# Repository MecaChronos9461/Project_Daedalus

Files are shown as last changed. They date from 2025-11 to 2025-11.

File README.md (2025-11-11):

# Project_Daedalus

# 🌍 Project Daedalus - Projeto Dédalo

Welcome! / Bem-vindo!

🇺🇸 Assistive Technology for Accessible CNC Programming Education (SENAI Vila Leopoldina + FRC 9461 MecaChronos

🇧🇷 Tecnologia Assistiva para o Ensino Acessível de Programação CNC (SENAI Vila Leopoldina + FRC 9461 MecaChronos)

**Choose your language / Escolha o idioma:**

- 🇺🇸 [English version](docs/en/index.md)
- 🇧🇷 [Versão em português](docs/pt/index.md)

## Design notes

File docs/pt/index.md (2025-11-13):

# Projeto Dédalo – Tecnologia Assistiva para o Ensino de CNC em Braille

**SENAI Vila Leopoldina + FRC 9461 MecaChronos**

Transforma o ensino de CNC e programação em uma experiência tátil e acessível.

[🇬🇧 Read in English](../en/index.md)

---

## 🎯 Visão Geral
O **Projeto Dédalo** transforma o ensino de CNC e de linguagens de programação em uma experiência **tátil e inclusiva**.  
Permite que estudantes cegos ou com baixa visão construam programas CNC utilizando **peças em Braille** sobre um **tabuleiro imantado**, representando a estrutura de comandos reais (G-code e lógica).

## 🧩 Guia Rápido
1. Acesse o [Guia Rápido](guia-rapido.md)
2. Baixe e imprima as peças 3D da pasta [`/stl`](https://github.com/MecaChronos9461/Project_Daedalus/tree/main/STL/pt)  
7. Monte o **tabuleiro imantado e as peças em Braille** (veja [Montagem Mecânica](https://github.com/MecaChronos9461/Project_Daedalus/blob/main/docs/pt/Projeto_Dedalo_Montagem.pdf)) 

## 🔗 Links Úteis
- [Onshape (CAD paramétrico)](https://cad.onshape.com/documents/f621f9364d6d382a1512dc64/w/f1545546a1fff06d9537397c/e/68e42de75a9061a4f078c312)
- [Tinkercad (modelos simplificados)](https://www.tinkercad.com/things/3EPu3dX8Huk-templatededalo)
- [Google Drive (manuais e PDFs)](https://drive.google.com/drive/folders/1ncHGz5KKSIpBdTNndNMXi23kKEn_FBrG?usp=sharing)

## 🧠 Objetivos
- Tornar o ensino de CNC e programação **acessível** a pessoas cegas ou com baixa visão  
- Fornecer um **kit educacional modular** com peças em Braille e documentação aberta  
- Apoiar docentes com **planos de aula, arquivos CAD e modelos STL**

## ⚙️ Licença
Distribuído sob **Creative Commons BY-SA 4.0**.  
Consulte o arquivo [LICENSE](../../LICENSE) para mais detalhes.

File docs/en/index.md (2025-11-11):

# Project Daedalus – Assistive Technology for Accessible CNC Education

**SENAI Vila Leopoldina + FRC 9461 MecaChronos**

Inclusive CNC programming through tactile Braille pieces and a magnetic board.

[🇧🇷 Read in Portuguese](../pt/index.md)

---

## 🎯 Overview
Project Daedalus transforms CNC and programming education into a **tactile and inclusive experience**.  
It allows students who are blind or visually impaired to build CNC programs using **Braille blocks** arranged on a **magnetic board**, simulating the structure of real G-code and logic.

## 🧩 Quick Start
1. Visit the [Quick Start Guide](quickstart.md)  
2. Download and print the 3D pieces from the [`/stl`](../../stl/) folder  
3. Assemble the **magnetic board and Braille blocks** (see [Mechanical Assembly](section-06_mechanical-assembly.md))  
4. Try the examples in [`/examples`](../../examples/) for your first lesson  

## 🔗 Useful Links
- [Onshape (CAD source)](../links.md#onshape)
- [Tinkercad (simplified models)](../links.md#tinkercad)
- [Google Drive (manuals and PDFs)](../links.md#google-drive)

## 🧠 Objectives
- Make CNC/programming education **inclusive** for blind and low-vision students  
- Provide a **modular educational kit** with Braille-based blocks and open documentation  
- Support teachers with ready-to-use **lesson plans, CAD files, and STL models**

## ⚙️ License
This project is distributed under **Creative Commons BY-SA 4.0**.  
See the [LICENSE](../../LICENSE) file for full details.

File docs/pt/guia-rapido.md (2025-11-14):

## 🧭 Guia Rápido

1. **Acesse o repositório principal:**  
   [GitHub - Projeto Dédalo](https://github.com/MecaChronos9461/Project_Daedalus)

2. **Baixe os arquivos 3D:**  
   [📂 STL](https://github.com/MecaChronos9461/Project_Daedalus/tree/main/STL/pt)

2. **Baixe os arquivos do tabuleiro:**  
   [📂 DWG](https://github.com/MecaChronos9461/Project_Daedalus/tree/main/SVG/pt)

3. **Monte o tabuleiro imantado e as peças em Braille:**  
   [🧩 Guia de Montagem Mecânica](https://github.com/MecaChronos9461/Project_Daedalus/blob/main/docs/pt/Projeto_Dedalo_Montagem.pdf)

4. **Assista aos tutoriais e veja como editar as peças:**  
   [🎥 Vídeos no YouTube](https://www.youtube.com/@FRC9461MecaChronos)

5. **Consulte os manuais e relatórios:**  
   [📘 Documentação Completa (PDF)](https://github.com/MecaChronos9461/Project_Daedalus/tree/main/docs/pt/desenhos_CAD)

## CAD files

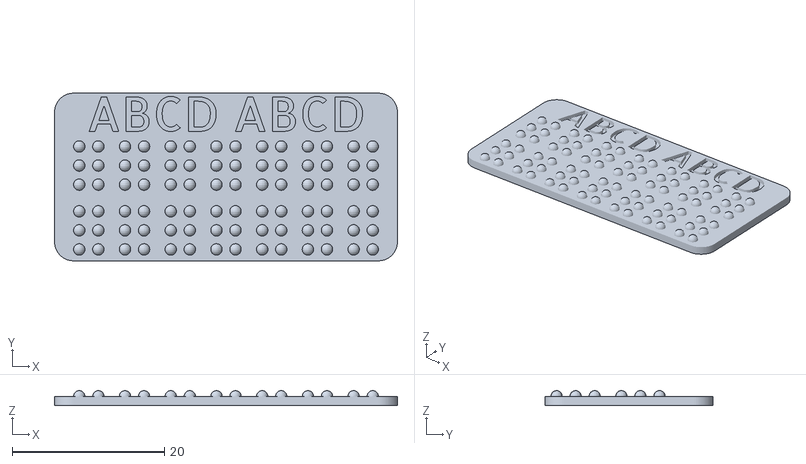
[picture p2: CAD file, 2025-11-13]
STL/pt/Etiqueta_2_Peças.stl
45.0 x 22.0 x 1.95

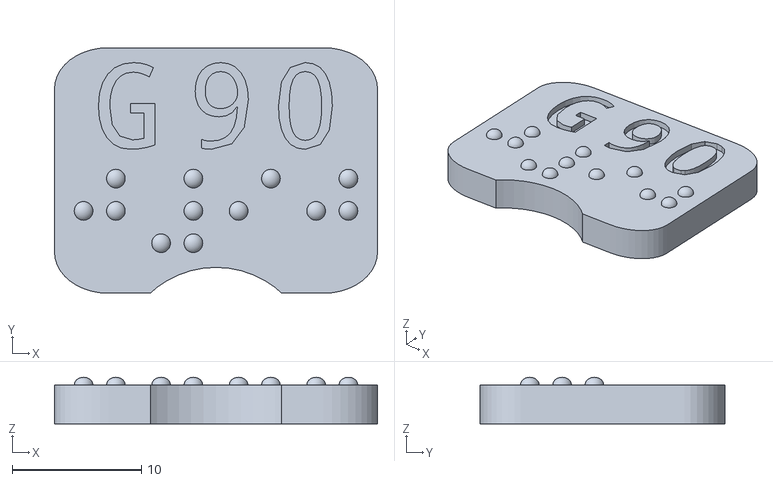
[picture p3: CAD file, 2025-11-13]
STL/pt/Pecas_GCODE/G90.stl
25.0 x 19.0 x 3.60

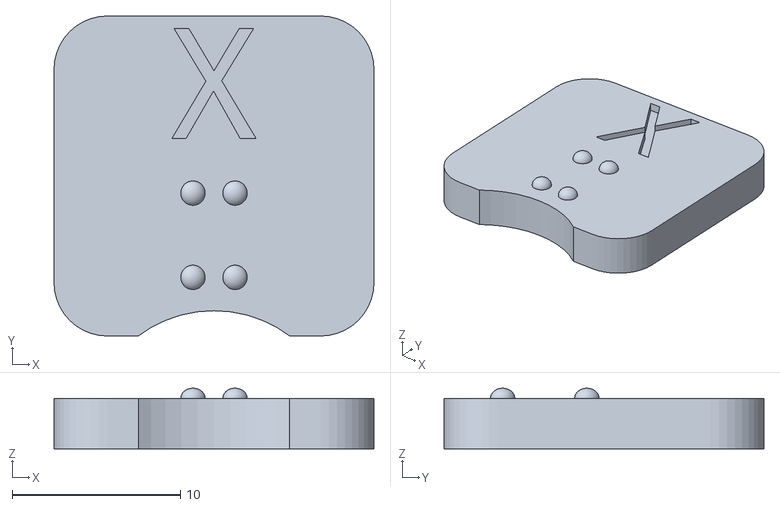
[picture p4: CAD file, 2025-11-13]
STL/pt/Pecas_Letras/X.stl
19.0 x 19.0 x 3.60

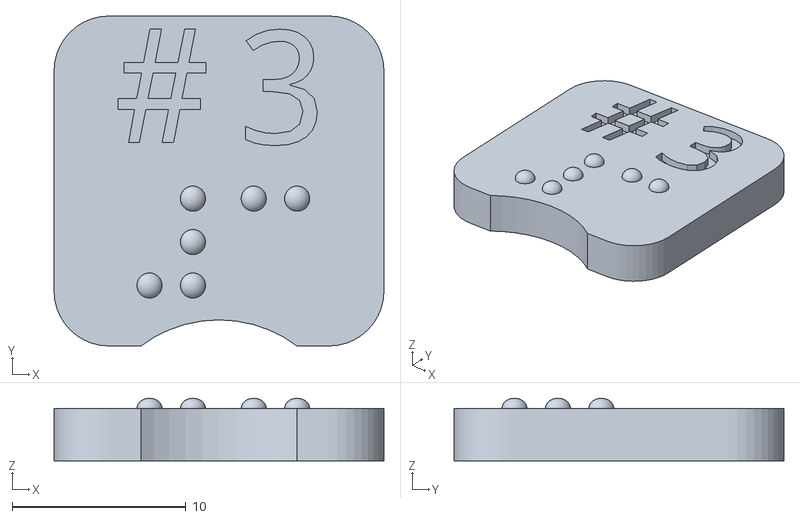
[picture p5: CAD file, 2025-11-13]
STL/pt/Pecas_Numeros/3.stl
19.0 x 19.0 x 3.60

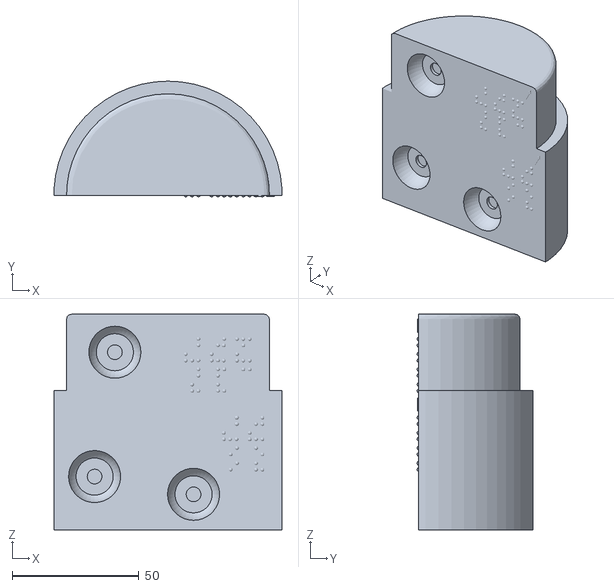
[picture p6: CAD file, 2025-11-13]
STL/pt/Pecas_Referencia/PEÇA_BLANK_LADO_1.stl
89.9 x 45.6 x 85.0

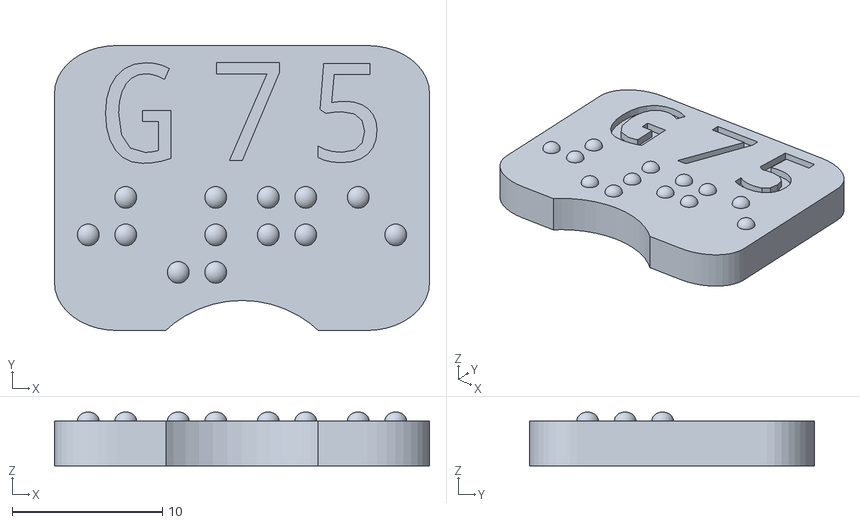
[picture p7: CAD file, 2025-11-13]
STL/pt/Pecas_GCODE/G75.stl
25.0 x 19.0 x 3.60

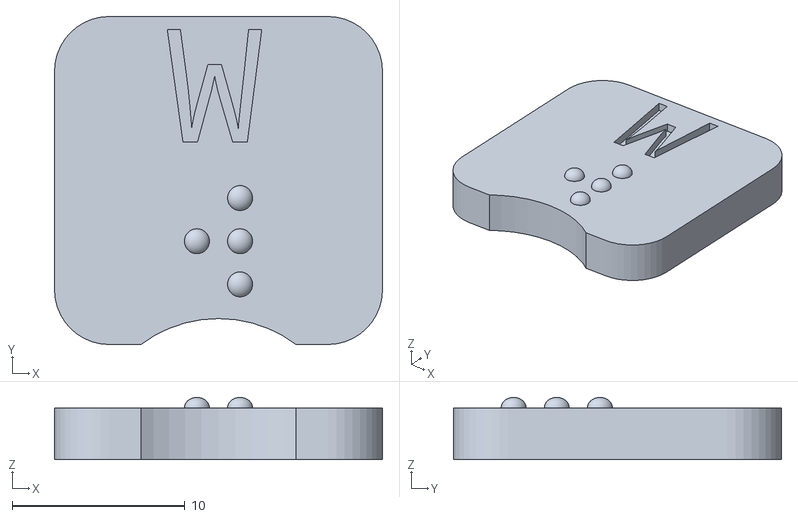
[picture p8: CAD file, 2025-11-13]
STL/pt/Pecas_Letras/W.stl
19.0 x 19.0 x 3.60

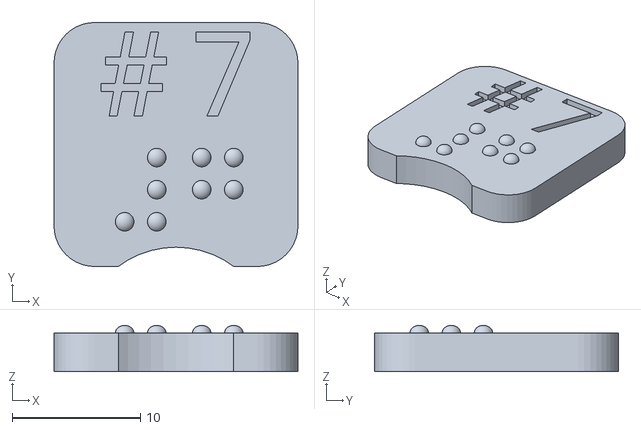
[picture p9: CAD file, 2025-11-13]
STL/pt/Pecas_Numeros/7.stl
19.0 x 19.0 x 3.60

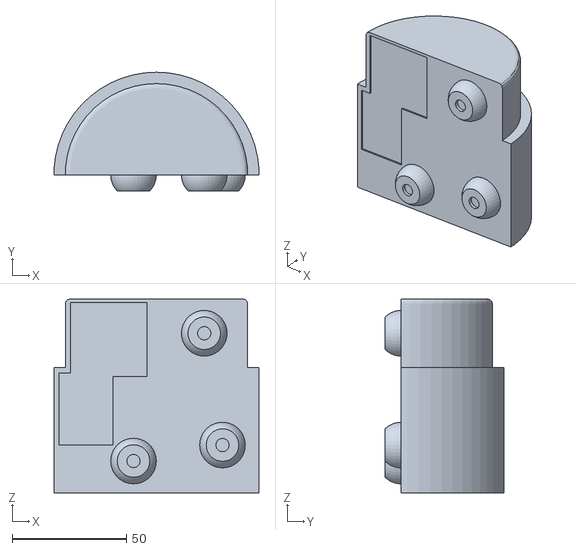
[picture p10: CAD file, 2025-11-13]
STL/pt/Pecas_Referencia/PEÇA_BLANK_LADO_2.stl
89.8 x 52.0 x 85.0

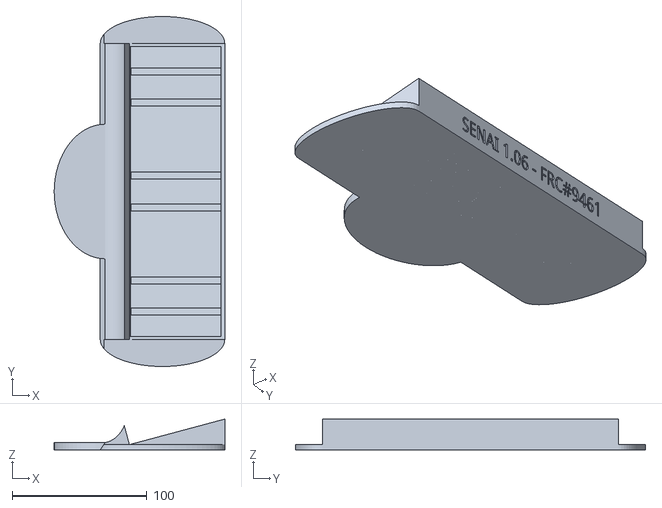
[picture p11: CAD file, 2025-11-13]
STL/pt/SuporteGaveteiro_v2.stl
126.7 x 259.9 x 22.9

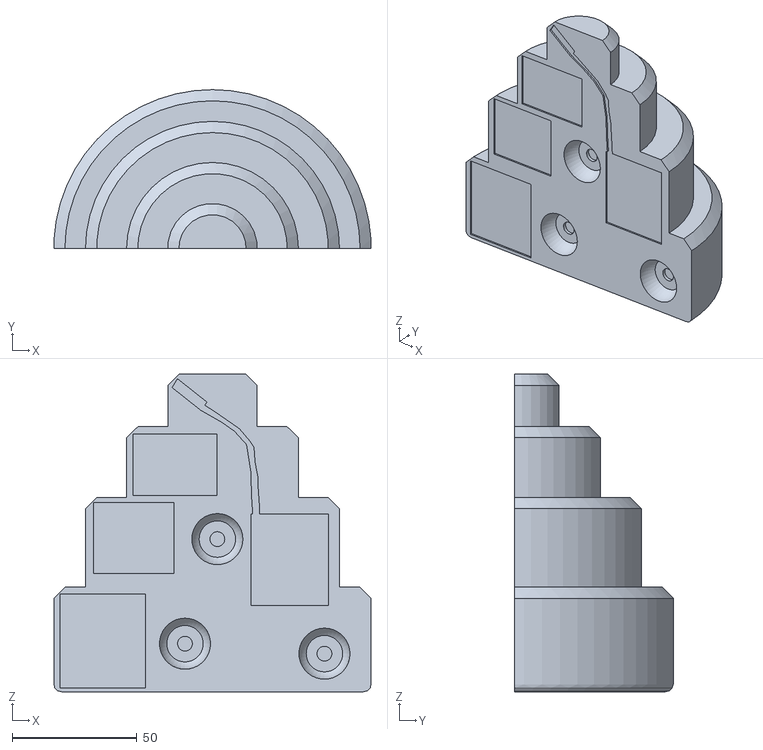
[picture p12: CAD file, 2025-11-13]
STL/pt/Pecas_Referencia/PEÇA CHANFRO_LADO_2.stl
127.3 x 63.7 x 127.5

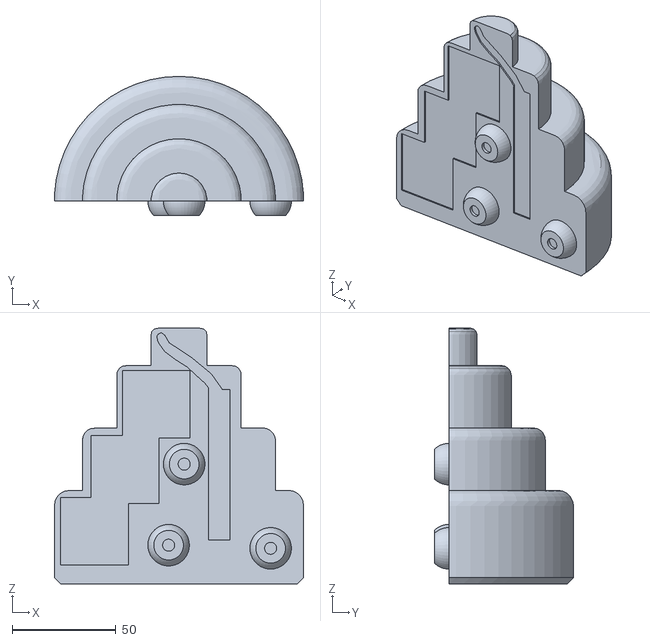
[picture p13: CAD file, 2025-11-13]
STL/pt/Pecas_Referencia/PEÇA_RAIO_LADO_2.stl
119.8 x 67.0 x 123.0

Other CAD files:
STL/pt/Pecas_GCODE/G03.stl
STL/pt/Pecas_Letras/P.stl
STL/pt/Pecas_Numeros/4.stl
STL/pt/Pecas_GCODE/G76.stl
STL/pt/Pecas_Letras/Z.stl
STL/pt/Pecas_Numeros/1.stl
STL/pt/Pecas_GCODE/F.15.stl
STL/pt/Pecas_GCODE/F.30.stl
STL/pt/Pecas_GCODE/G00.stl
STL/pt/Pecas_GCODE/G01.stl
STL/pt/Pecas_GCODE/G02.stl
STL/pt/Pecas_GCODE/G21.stl
STL/pt/Pecas_GCODE/G40.stl
STL/pt/Pecas_GCODE/G41.stl
STL/pt/Pecas_GCODE/G42.stl
STL/pt/Pecas_GCODE/G54.stl
STL/pt/Pecas_GCODE/G70.stl
STL/pt/Pecas_GCODE/G71.stl
STL/pt/Pecas_GCODE/G72.stl
STL/pt/Pecas_GCODE/G92.stl
STL/pt/Pecas_GCODE/G96.stl
STL/pt/Pecas_GCODE/G97.stl
STL/pt/Pecas_GCODE/M03.stl
STL/pt/Pecas_GCODE/M04.stl
STL/pt/Pecas_GCODE/M08.stl
STL/pt/Pecas_GCODE/M09.stl
STL/pt/Pecas_Letras/K.stl
STL/pt/Pecas_Letras/N.stl
STL/pt/Pecas_Letras/Q.stl
STL/pt/Pecas_Letras/S.stl
STL/pt/Pecas_Letras/U.stl
STL/pt/Pecas_Numeros/0.stl
STL/pt/Pecas_Numeros/2.stl
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

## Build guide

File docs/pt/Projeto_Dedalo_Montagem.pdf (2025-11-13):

Anexo C – Guia de montagem e armazenamento do kit.

C.1 Materiais necessários
Tabela C.1 – Materiais necessários
Categoria | Item | Especificação / Medida
Estrutura | Chapa de acrílico | 3 mm
Estrutura | Chapa metálica ferromagnética | 0,5 mm
Fixação | Cola instantânea | Cianoacrilato
Fixação | Ímãs de neodímio | Ø5 × 1 mm
Impressão 3D | Filamento PLA | Ø1,75 mm
Impressão 3D | Impressora 3D | —
Armazenamento | Gaveteiro modular plástico | 220 × 150 × 80 mm (16 gavetas)
Armazenamento | Base impressa 3D com inclinação de 15° | —

Fonte: Autor (2025).

C.2 Montagem do tabuleiro magnético

### 1. Corte as placas de acrílico de acordo com os arquivos .DWG na máquina

de corte a laser e a chapa metálica nas dimensões especificadas (345 ×

245 mm).

### 2. Cole as três camadas na seguinte ordem:

- Base em acrílico de 3 mm;
- Chapa metálica ferromagnética central (0,5 mm);
- Tampa frontal em acrílico de 3 mm, com 14 canais de 20 mm de

altura.

3. Utilize cola cianoacrilato para fixação, aplicando uniformemente nas bordas.
4. Aguarde a secagem completa antes de inserir as peças Braille.

Figura C.1 – Estrutura do tabuleiro magnético com três camadas (vista explodida)

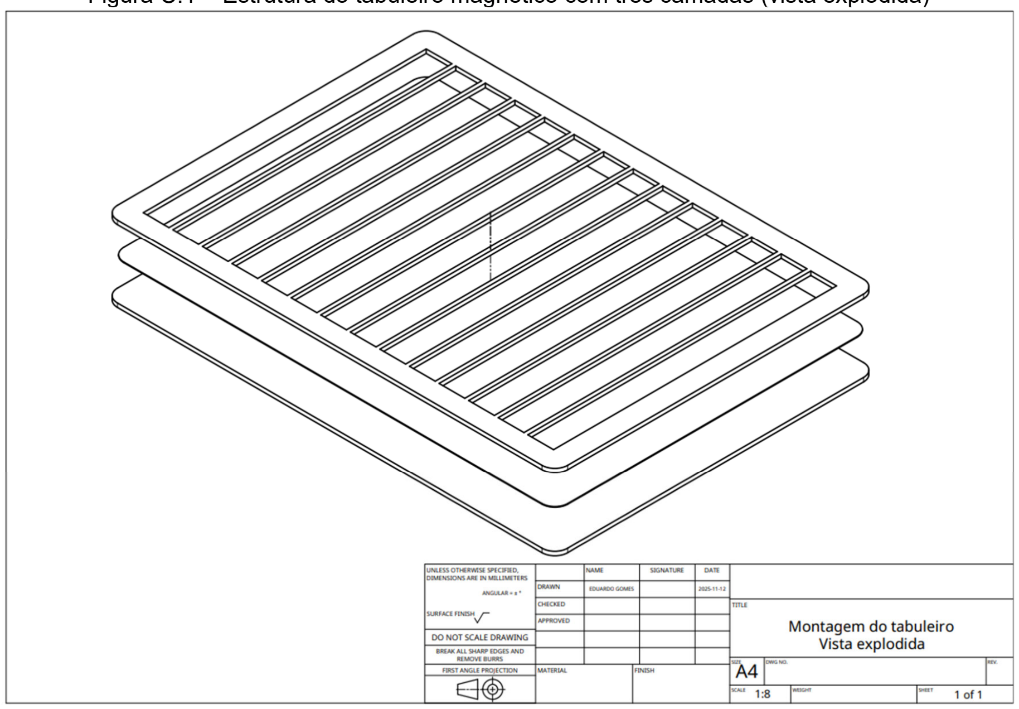
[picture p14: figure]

Fonte: Acervo do Projeto Dédalo (2025).

C.3 Montagem das peças Braille

### 1. Imprima as peças em PLA 1,75 mm utilizando os seguintes parâmetros de

impressão:

- Altura da camada: 0,20 mm
- Preenchimento (infill): padrão Grid com 15%
- Paredes externas: 2
- Camadas superiores: 3
- Camadas inferiores: 2
- Temperatura do bico: 215 °C
- Temperatura da mesa: 65 °C

### 2. Após a impressão, insira o ímã de neodímio (Ø 5 × 1 mm) no furo traseiro

de cada peça e fixe com cola instantânea (cianoacrilato).

### 3. Certifique-se de que o chanfro inferior da peça esteja orientado

corretamente, pois ele indica o lado inferior e a posição de leitura.

### 4. Teste o encaixe e a magnetização das peças sobre o tabuleiro antes do

uso em sala.

Observação: As temperaturas de impressão podem variar conforme o modelo da impressora 3D e a marca do filamento utilizado. As velocidades de impressão variam de acordo com os limites da impressora 3D utilizada.

Figura C.2 – Peças Braille com inserção dos ímãs traseiros

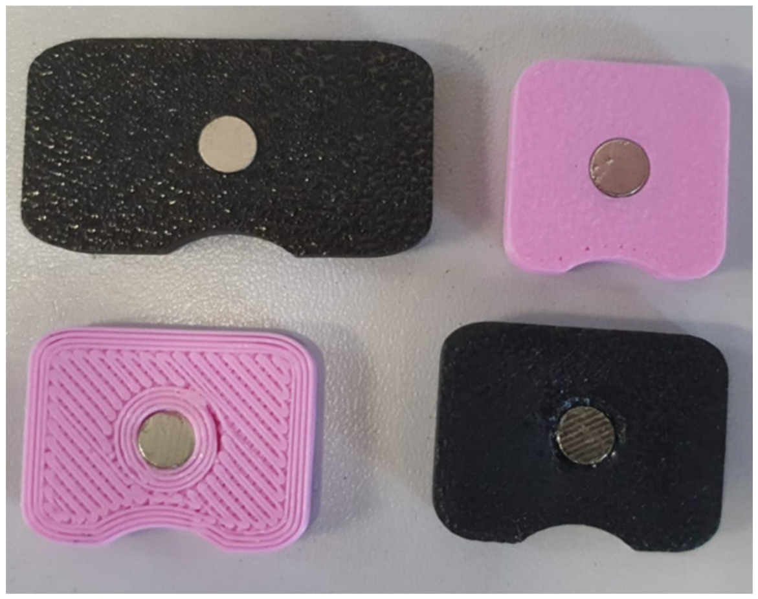
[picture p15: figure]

Fonte: Acervo do Projeto Dédalo (2025).

C.4 Montagem e organização do gaveteiro

### 1. Utilize um gaveteiro plástico modular de 16 compartimentos, com

dimensões aproximadas de 150 × 220 × 80 mm (altura × comprimento ×

largura).

### 2. Posicione o gaveteiro sobre a base de apoio impressa em 3D, projetada

com inclinação de 15°, o que garante o fechamento automático das

gavetas e evita quedas acidentais das peças em caso de impacto ou

deslocamento.

### 3. Fixe o gaveteiro à base utilizando super cola (cianoacrilato), aplicando

uniformemente nas áreas de contato para garantir aderência e estabilidade.

### 4. Insira em cada gaveta uma etiqueta em Braille impressa em 3D, indicando

o código ou o tipo de peça armazenada.

### 5. Organize as peças conforme a sequência lógica do conteúdo didático

(letras, números, comandos, etc.), facilitando a localização durante as

atividades práticas.

Figura C.3 – Gaveteiro de múltiplos compartimentos apoiado em base inclinada a 15°

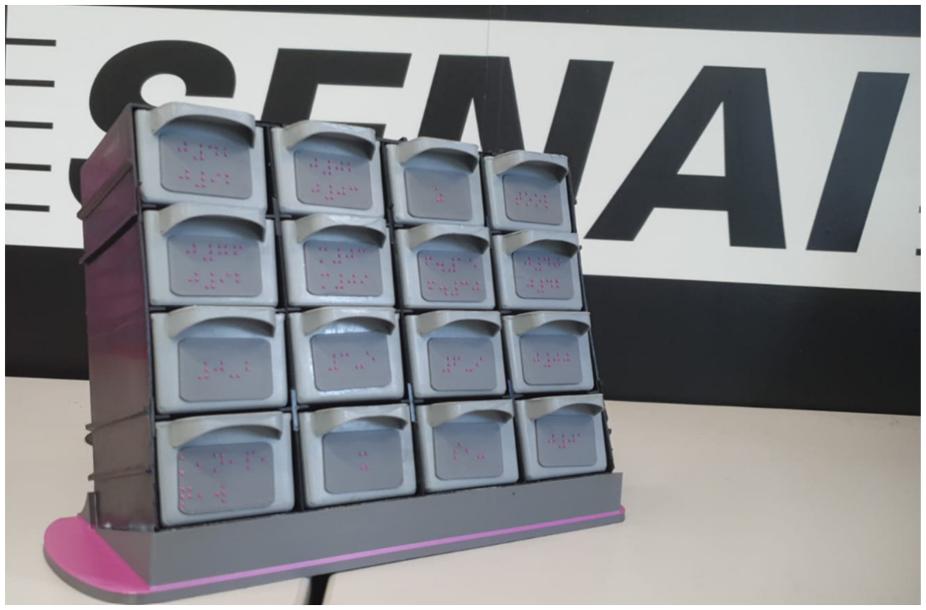
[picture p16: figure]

Fonte: Acervo do Projeto Dédalo (2025).

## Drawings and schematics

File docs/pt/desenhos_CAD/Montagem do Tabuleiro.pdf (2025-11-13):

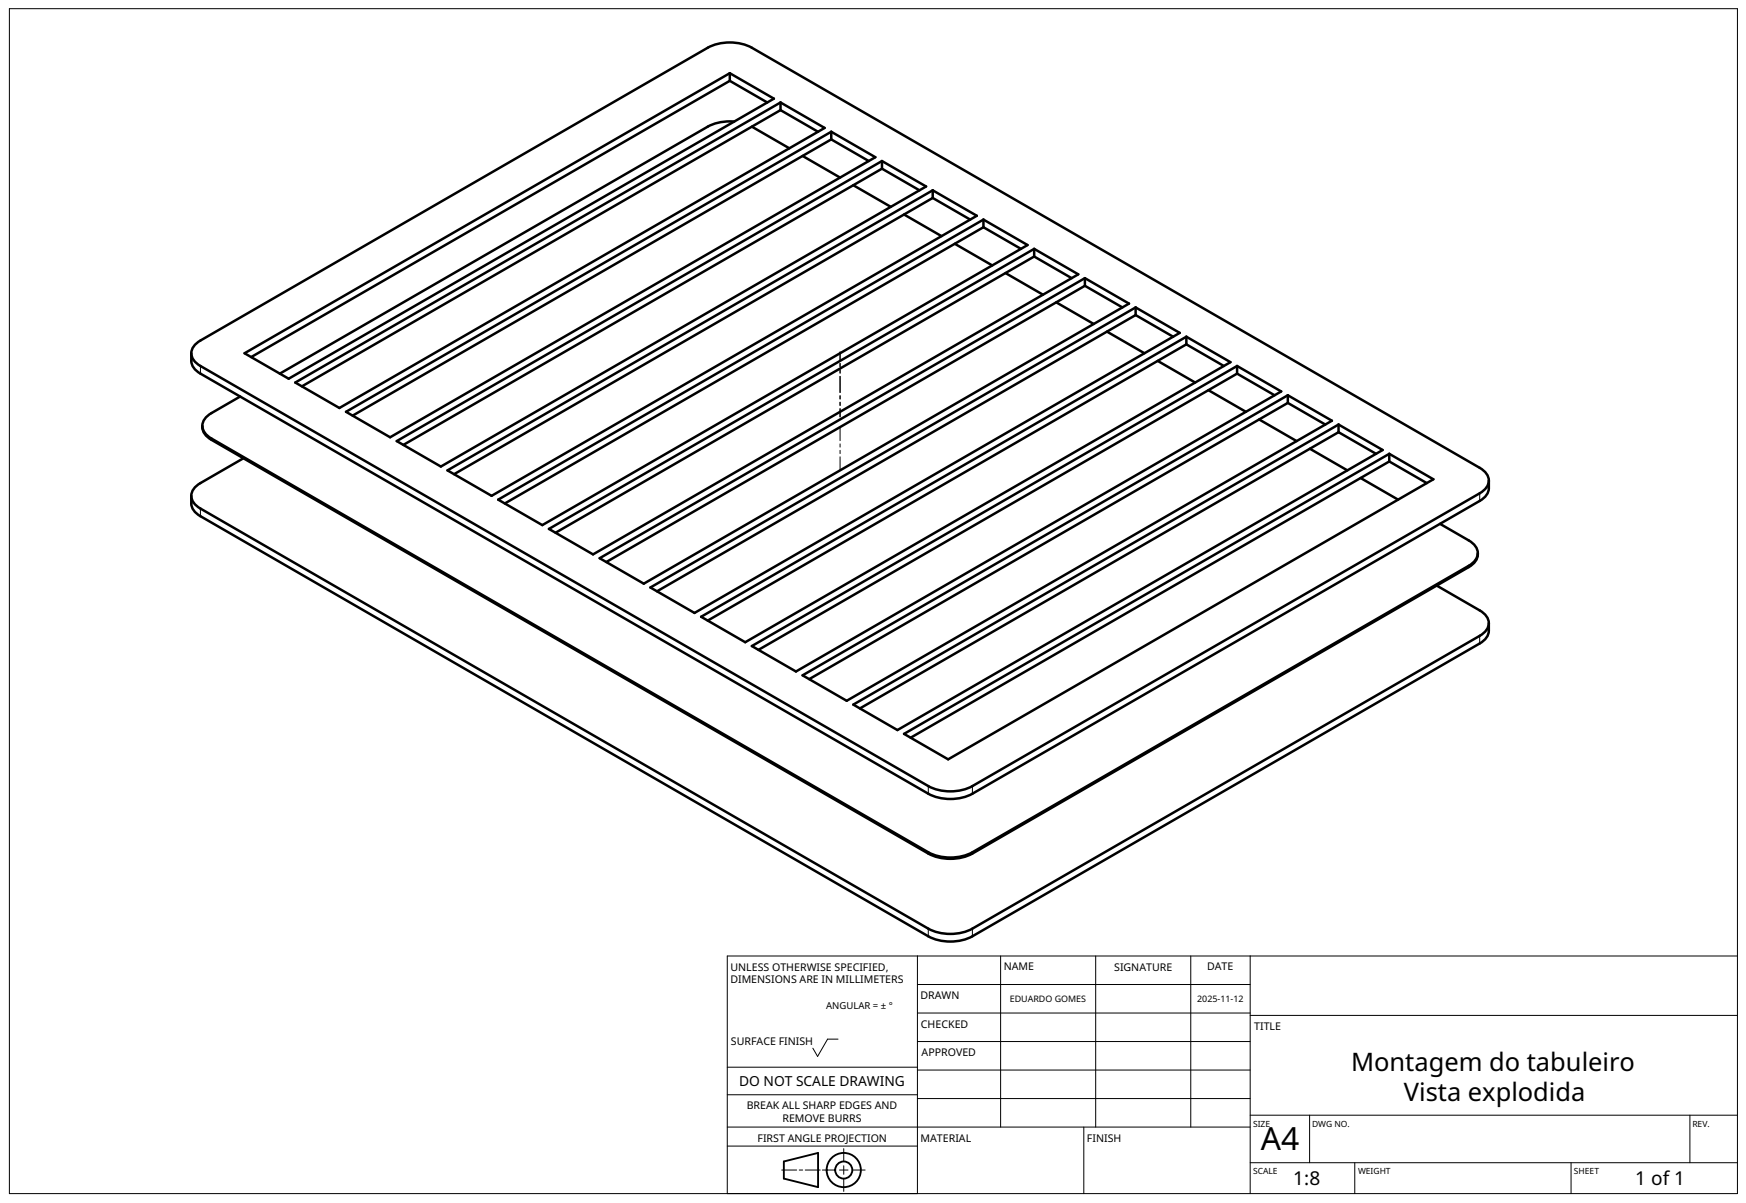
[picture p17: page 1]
MATERIAL; FINISH

UNLESS OTHERWISE SPECIFIED, DIMENSIONS ARE IN MILLIMETERS ANGULAR = ± ° SURFACE FINISH | | NAME | SIGNATURE | DATE

DRAWN | EDUARDO GOMES | | 2025-11-12

CHECKED | | | | TITLE Montagem do tabuleiro Vista explodida

APPROVED

DO NOT SCALE DRAWING

BREAK ALL SHARP EDGES AND

REMOVE BURRS
FIRST ANGLE PROJECTION

SIZE A4 | DWG NO. | REV.

SCALE 1:8 | WEIGHT | SHEET 1 of 1

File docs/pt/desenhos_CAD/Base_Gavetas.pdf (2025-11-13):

228

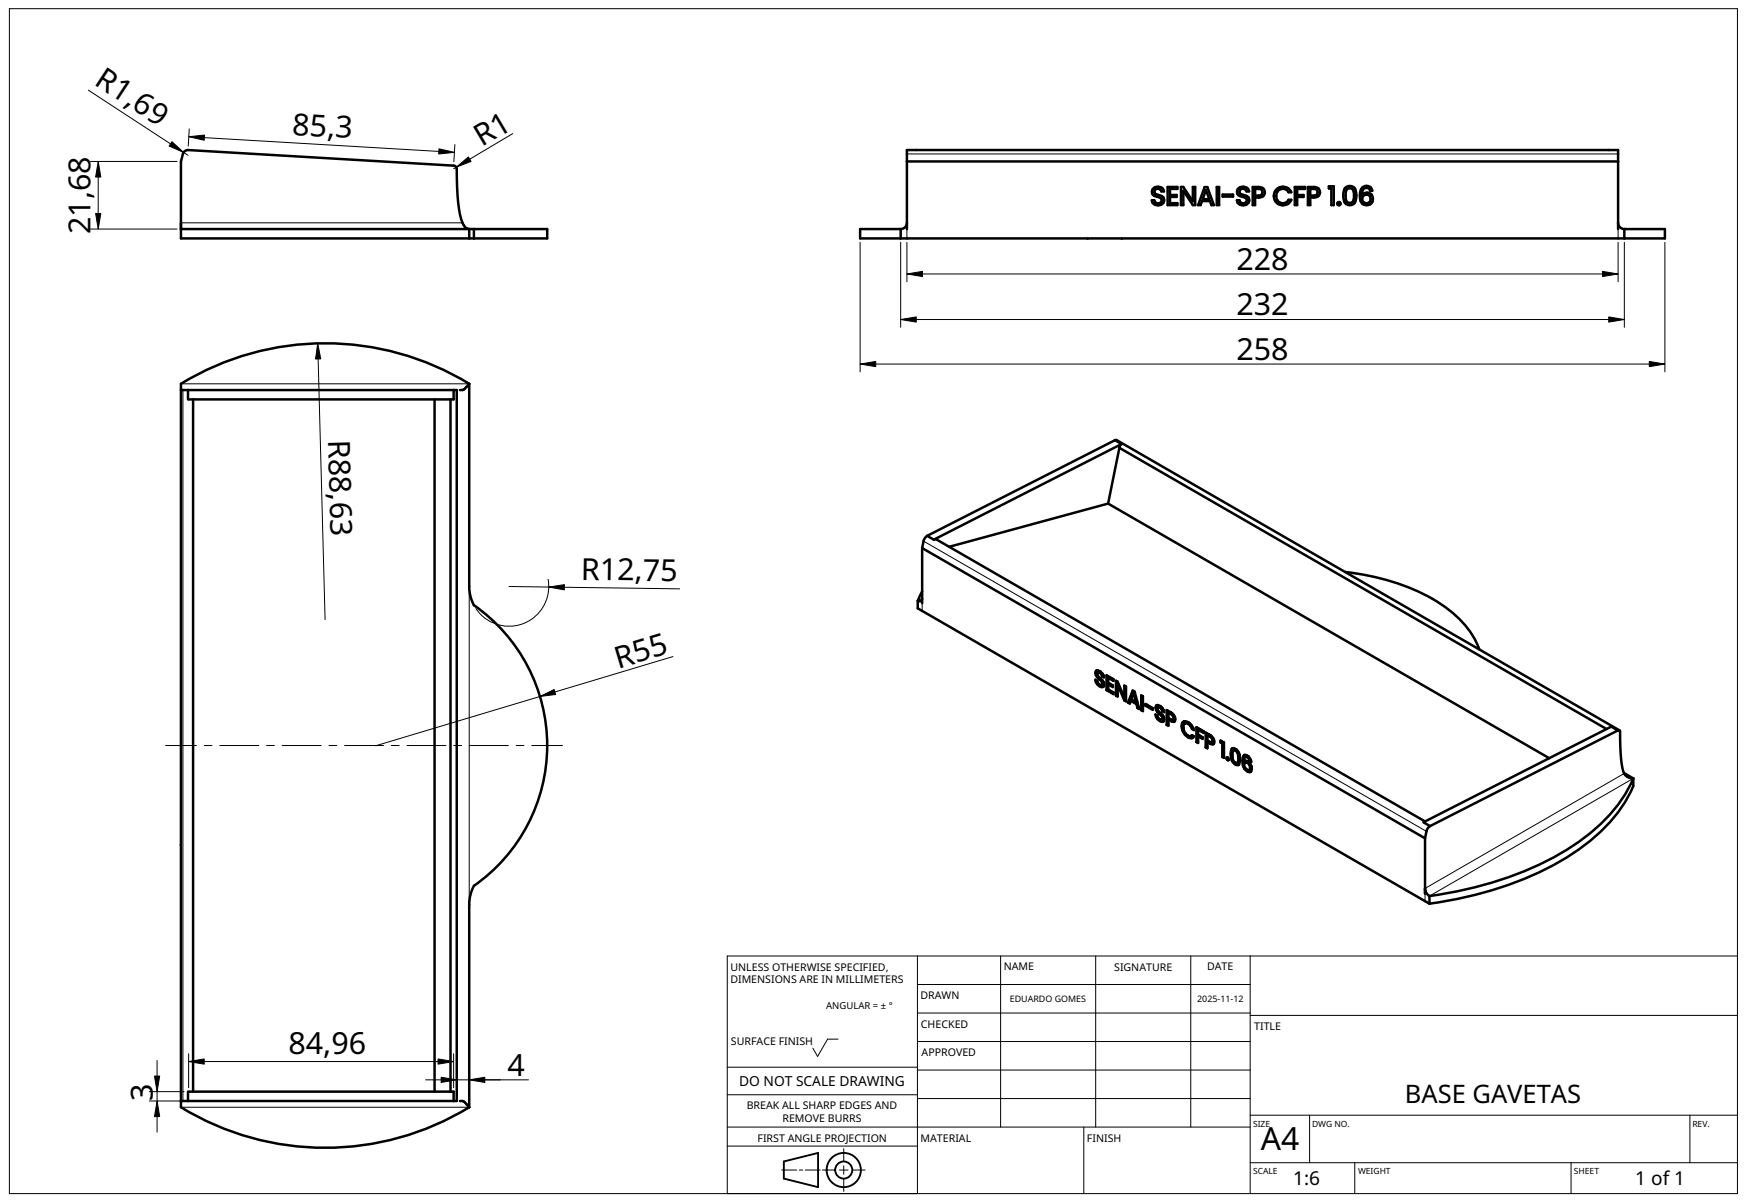
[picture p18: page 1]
MATERIAL; FINISH

UNLESS OTHERWISE SPECIFIED, DIMENSIONS ARE IN MILLIMETERS ANGULAR = ± ° SURFACE FINISH | | NAME | SIGNATURE | DATE

DRAWN | EDUARDO GOMES | | 2025-11-12

CHECKED | | | | TITLE BASE GAVETAS

APPROVED

DO NOT SCALE DRAWING

BREAK ALL SHARP EDGES AND

REMOVE BURRS
FIRST ANGLE PROJECTION

SIZE A4 | DWG NO. | REV.

SCALE 1:6 | WEIGHT | SHEET 1 of 1

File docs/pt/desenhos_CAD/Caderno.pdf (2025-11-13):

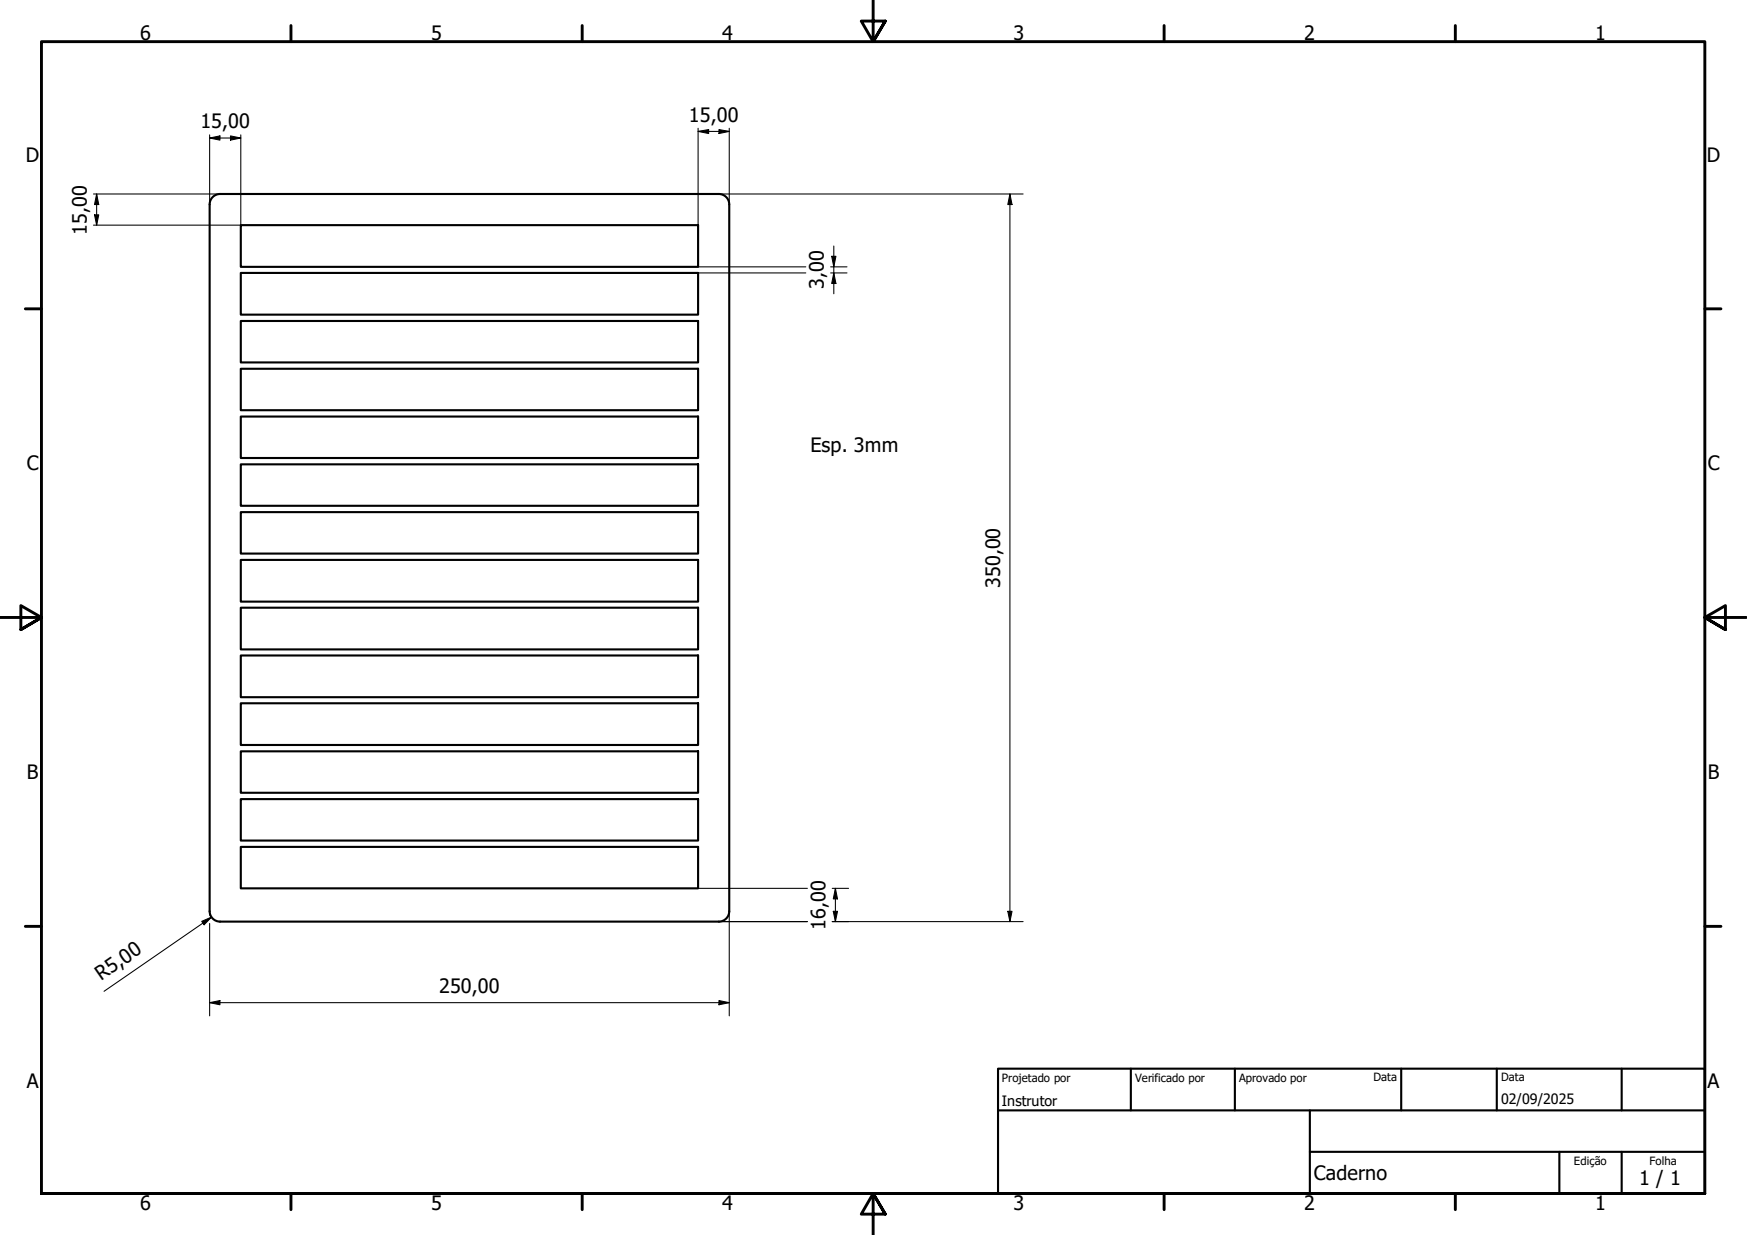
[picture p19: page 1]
Projetado por; Verificado por; Aprovado por; Data; Esp. 3mm

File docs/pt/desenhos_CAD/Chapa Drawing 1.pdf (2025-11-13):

A

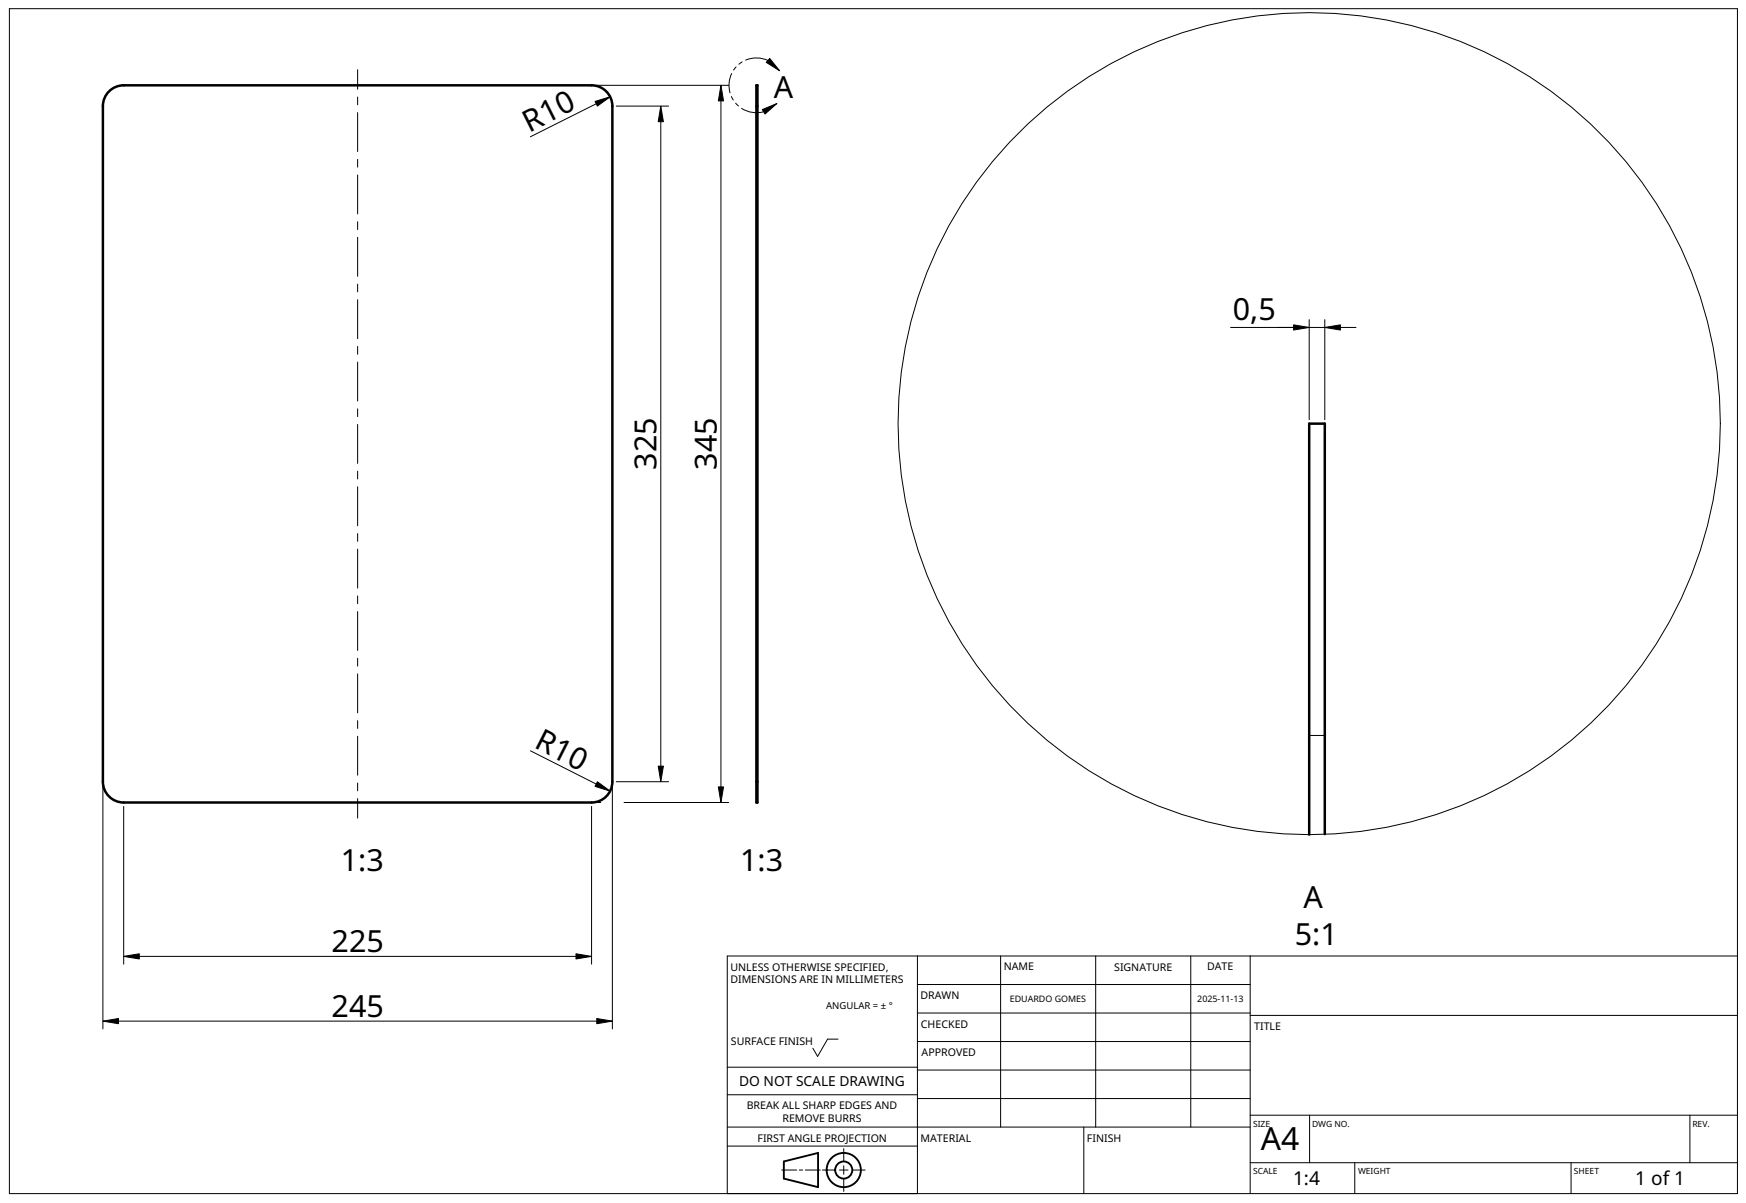
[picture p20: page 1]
MATERIAL; FINISH

UNLESS OTHERWISE SPECIFIED, DIMENSIONS ARE IN MILLIMETERS ANGULAR = ± ° SURFACE FINISH | | NAME | SIGNATURE | DATE

DRAWN | EDUARDO GOMES | | 2025-11-13

CHECKED | | | | TITLE

APPROVED

DO NOT SCALE DRAWING

BREAK ALL SHARP EDGES AND

REMOVE BURRS
FIRST ANGLE PROJECTION

SIZE A4 | DWG NO. | REV.

SCALE 1:4 | WEIGHT | SHEET 1 of 1

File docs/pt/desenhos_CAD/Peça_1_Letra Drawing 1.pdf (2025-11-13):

Ø5,25

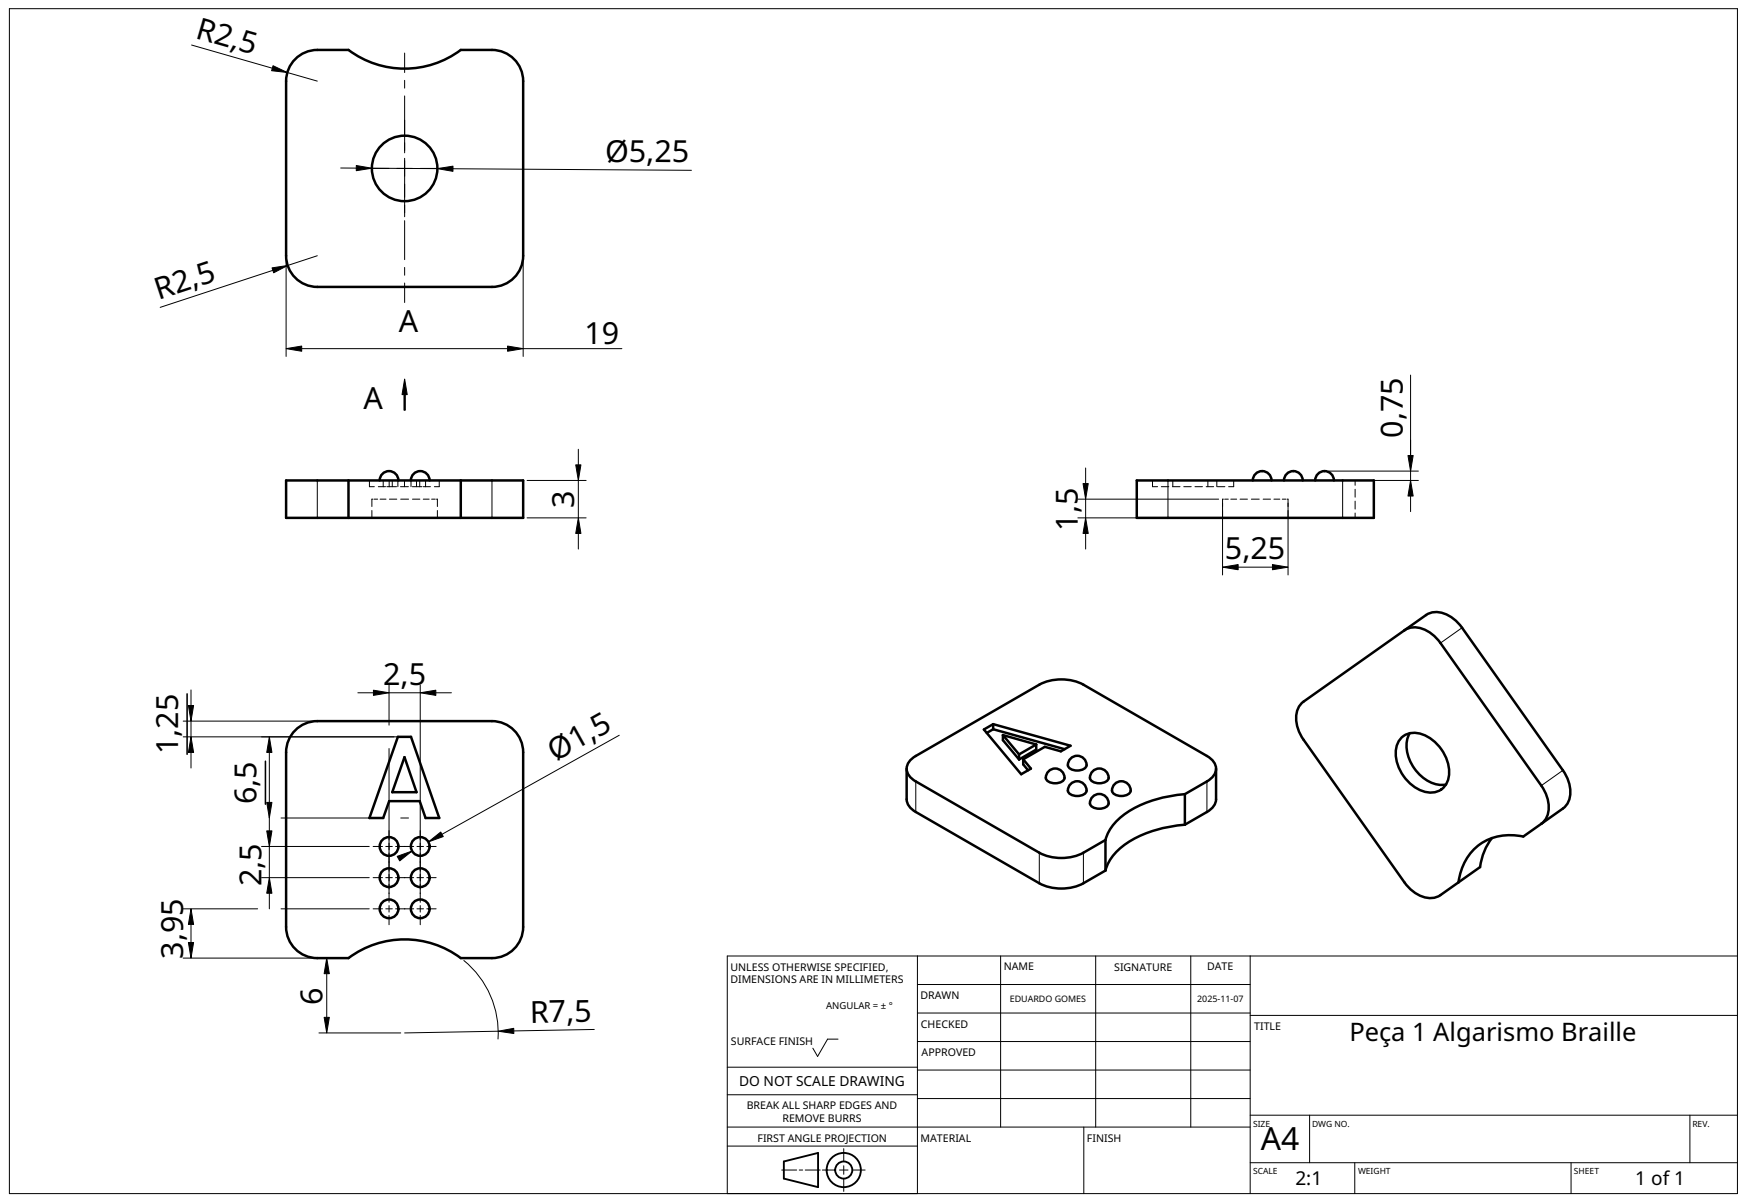
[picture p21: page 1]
MATERIAL; FINISH

UNLESS OTHERWISE SPECIFIED, DIMENSIONS ARE IN MILLIMETERS ANGULAR = ± ° SURFACE FINISH | | NAME | SIGNATURE | DATE

DRAWN | EDUARDO GOMES | | 2025-11-07

CHECKED | | | | TITLE Peça 1 Algarismo Braille

APPROVED

DO NOT SCALE DRAWING

BREAK ALL SHARP EDGES AND

REMOVE BURRS
FIRST ANGLE PROJECTION

SIZE A4 | DWG NO. | REV.

SCALE 2:1 | WEIGHT | SHEET 1 of 1

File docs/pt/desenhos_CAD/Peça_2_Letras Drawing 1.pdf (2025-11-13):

R2,5

R2,53,95 2,5

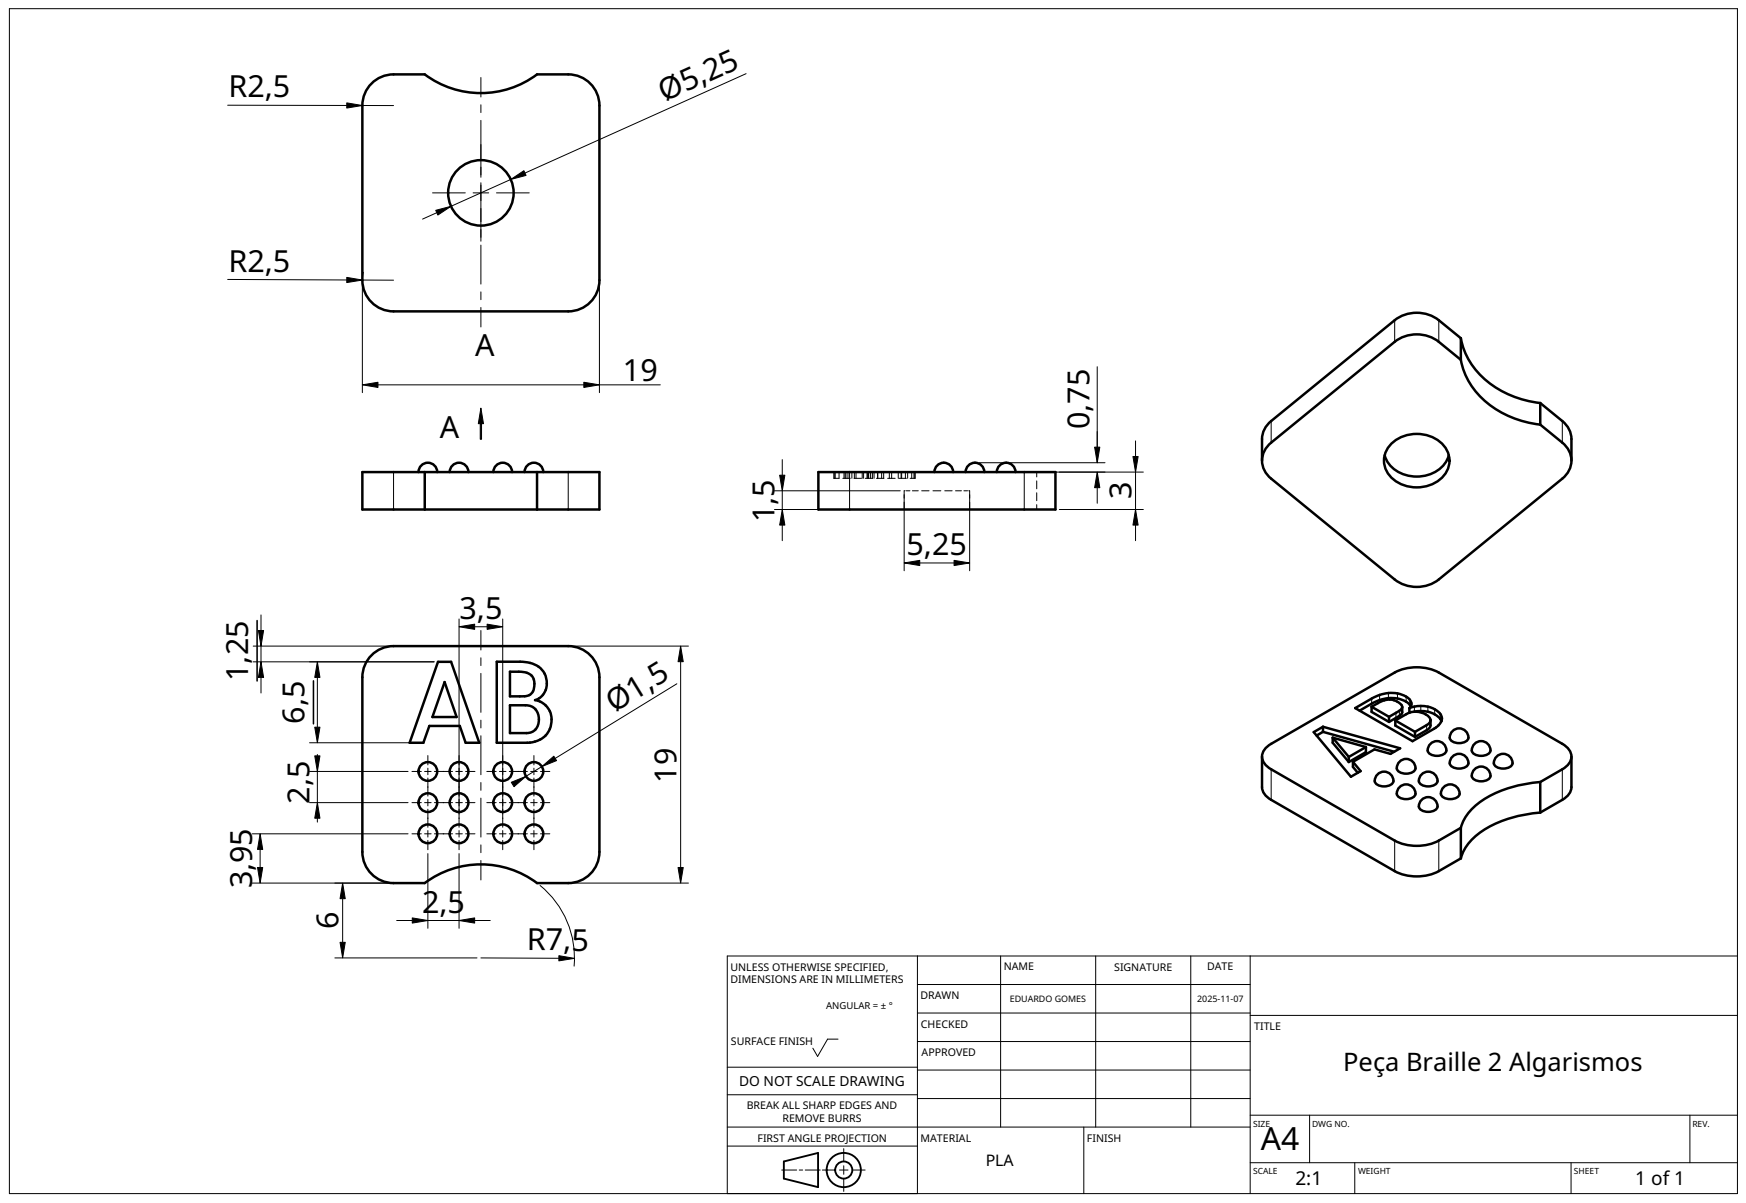
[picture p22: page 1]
MATERIAL; PLA; FINISH

UNLESS OTHERWISE SPECIFIED, DIMENSIONS ARE IN MILLIMETERS ANGULAR = ± ° SURFACE FINISH | | NAME | SIGNATURE | DATE

DRAWN | EDUARDO GOMES | | 2025-11-07

CHECKED | | | | TITLE Peça Braille 2 Algarismos

APPROVED

DO NOT SCALE DRAWING

BREAK ALL SHARP EDGES AND

REMOVE BURRS
FIRST ANGLE PROJECTION

SIZE A4 | DWG NO. | REV.

SCALE 2:1 | WEIGHT | SHEET 1 of 1
